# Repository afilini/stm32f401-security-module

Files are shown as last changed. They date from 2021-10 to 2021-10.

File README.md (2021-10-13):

# STM32F401 Security Module

<div style="width: 100%; display: flex; justify-content: space-between;">
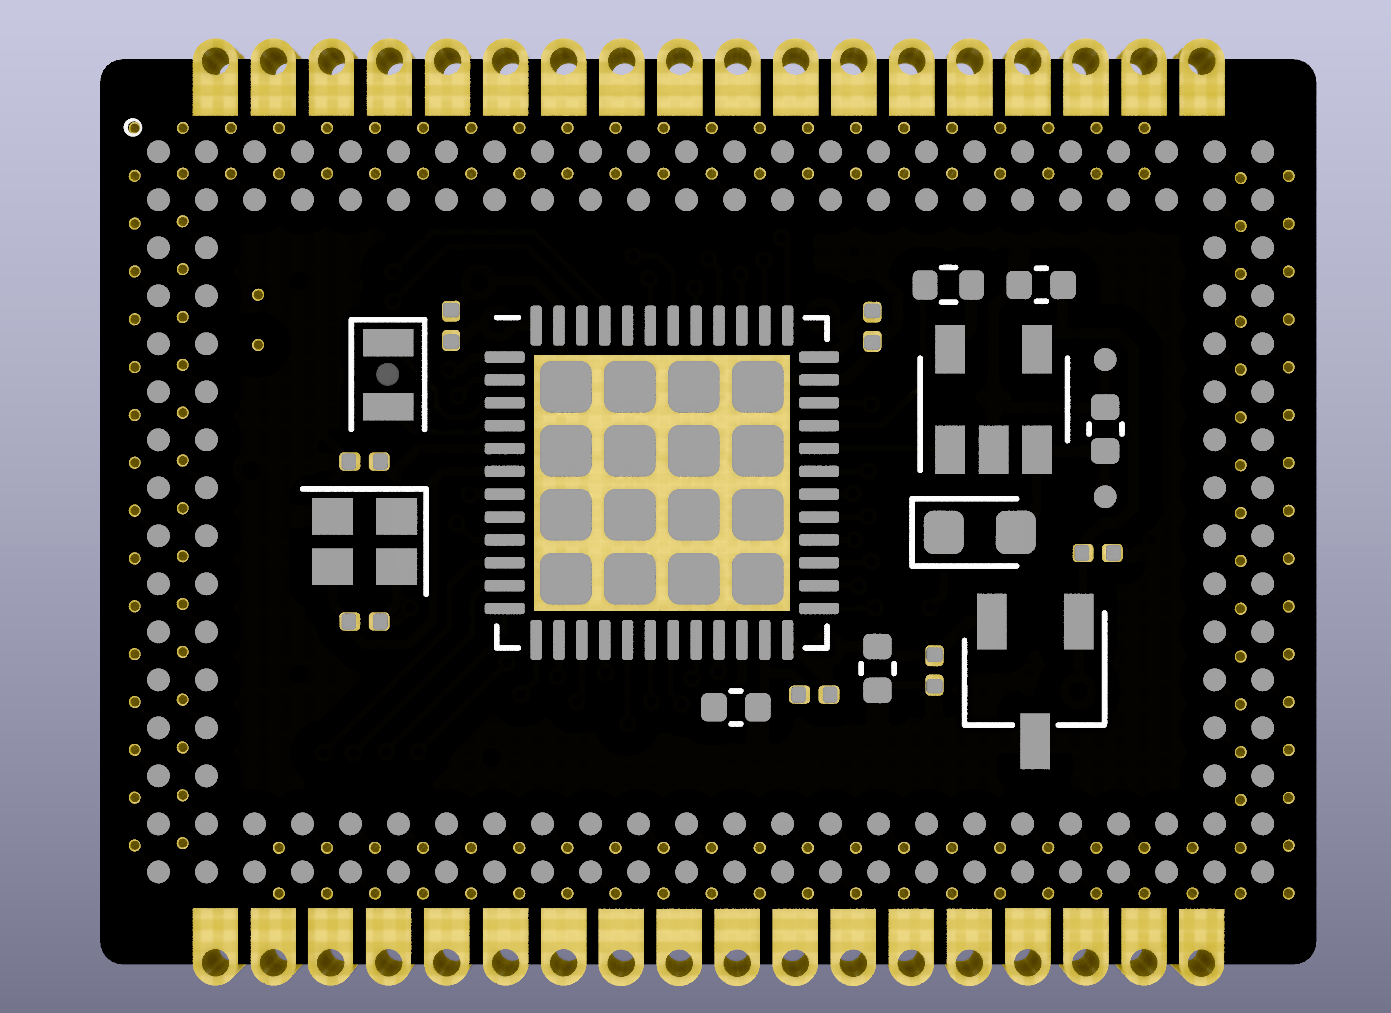
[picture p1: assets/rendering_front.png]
  
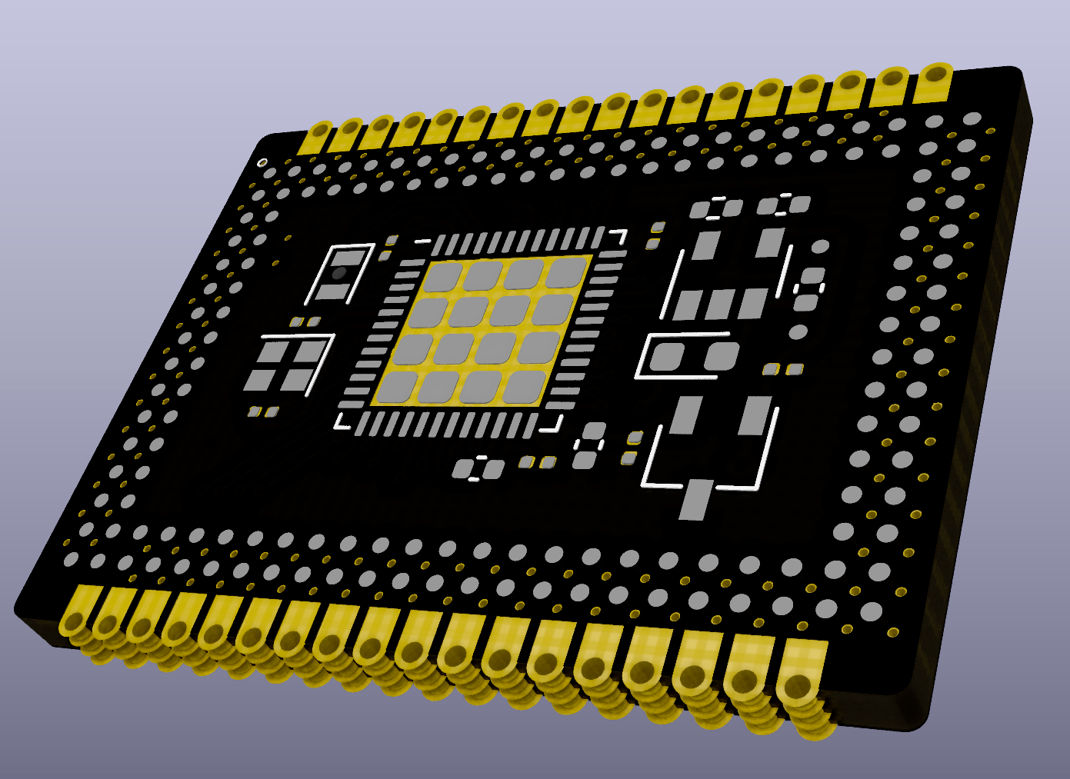
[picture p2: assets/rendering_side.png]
  
</div>

## License

This work is licensed under the [CERN Open Hardware Licence Version 2 - Strongly Reciprocal](LICENSE) license.

## Supporters

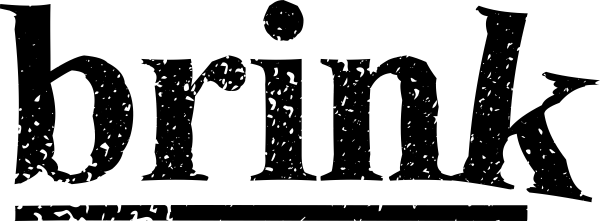
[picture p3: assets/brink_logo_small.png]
Brink logo


This work is supported by a [Brink](https://brink.dev) grant.

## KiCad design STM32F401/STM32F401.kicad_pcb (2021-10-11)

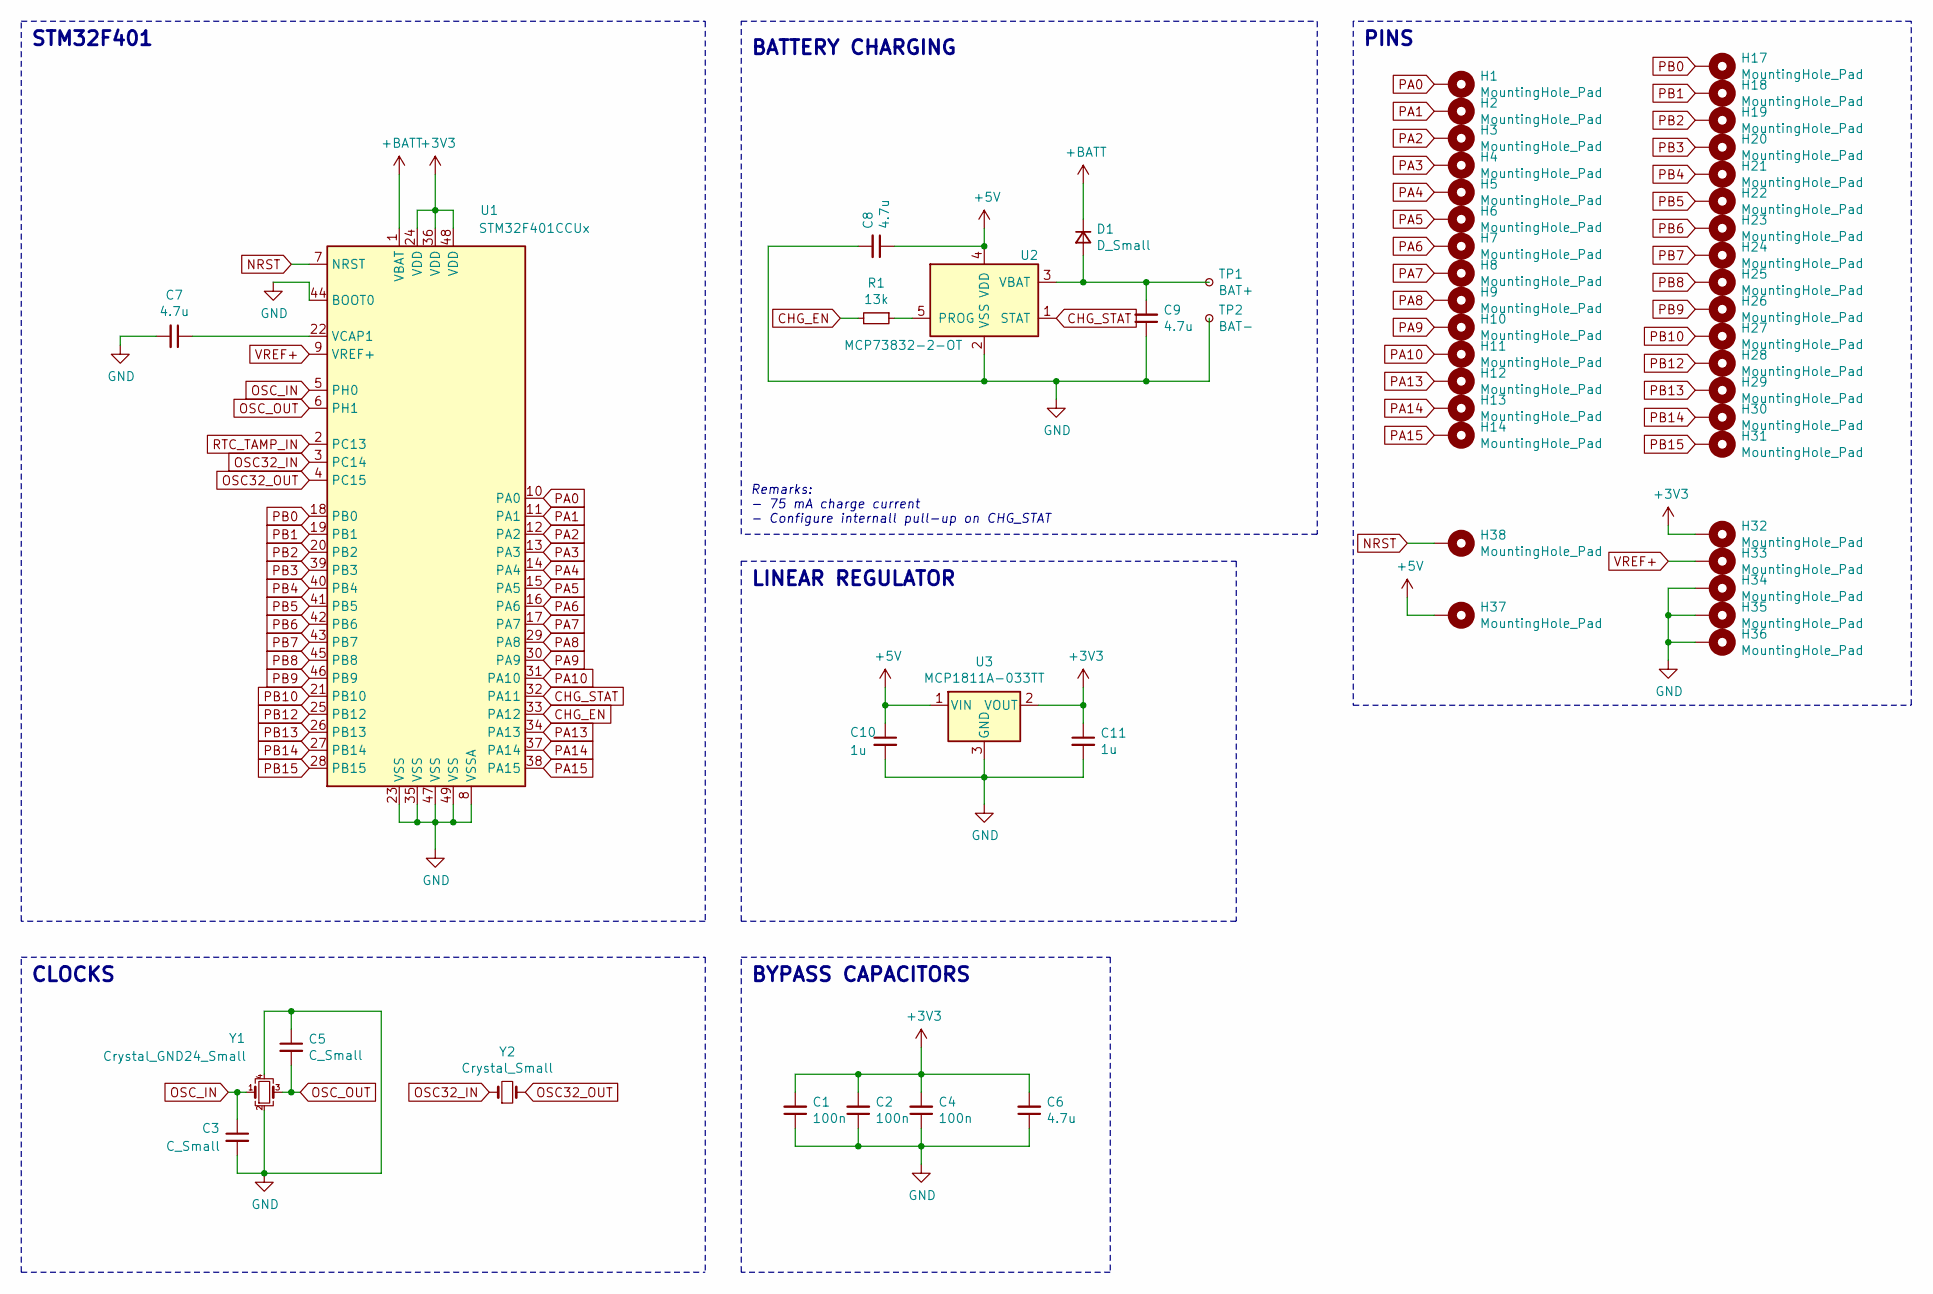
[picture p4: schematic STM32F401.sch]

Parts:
C1, C2, C4: 100n; C_0201_0603Metric
C3, C5: C_Small; C_0201_0603Metric
C6, C7, C8, C9: 4.7u; C_0402_1005Metric
C10, C11: 1u; C_0201_0603Metric
D1: D_Small; D_0603_1608Metric
H1, H2, H3, H4, H5, H6, H7, H8, H9, H10, H11, H12, H13, H14, H17, H18, H19, H20, H21, H22, H23, H24, H25, H26, H27, H28, H29, H30, H31, H32, H33, H34, H35, H36, H37, H38: MountingHole_Pad; CastellatedHole_0.6mm
R1: 13k; R_0402_1005Metric
TP1: BAT+; BatteryPad
TP2: BAT-; BatteryPad
U1: STM32F401CCUx; QFN-48-1EP_7x7mm_P0.5mm_EP5.6x5.6mm
U2: MCP73832-2-OT; SOT-23-5
U3: MCP1811A-033TT; TSOT-23
Y1: Crystal_GND24_Small; Crystal_SMD_2016-4Pin_2.0x1.6mm
Y2: Crystal_Small; Crystal_SMD_2012-2Pin_2.0x1.2mm

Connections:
+3V3: C1.2, C2.2, C4.2, C6.2, C11.1, H32.1, U1.24 (VDD), U1.36 (VDD), U1.48 (VDD), U3.2 (VOUT)
+5V: C8.1, C10.1, H37.1, U2.4 (VDD), U3.1 (VIN)
+BATT: D1.1 (K), U1.1 (VBAT)
CHG_EN: R1.2, U1.33 (PA12)
CHG_STAT: U1.32 (PA11), U2.1 (STAT)
GND: C1.1, C2.1, C3.2, C4.1, C5.1, C6.1, C7.2, C8.2, C9.1, C10.2, C11.2, H34.1, H35.1, H36.1, TP2.1, U1.8 (VSSA), U1.23 (VSS), U1.35 (VSS), U1.44 (BOOT0), U1.47 (VSS), U1.49 (VSS), U2.2 (VSS), U3.3 (GND), Y1.2, Y1.4
NRST: H38.1, U1.7 (NRST)
unnamed: C7.1, U1.22 (VCAP1)
unnamed: C9.2, D1.2 (A), TP1.1, U2.3 (VBAT)
unnamed: R1.1, U2.5 (PROG)
OSC32_IN: U1.3 (PC14), Y2.1
OSC32_OUT: U1.4 (PC15), Y2.2
OSC_IN: C3.1, U1.5 (PH0), Y1.1
OSC_OUT: C5.2, U1.6 (PH1), Y1.3
PA0: H1.1, U1.10 (PA0)
PA1: H2.1, U1.11 (PA1)
PA2: H3.1, U1.12 (PA2)
PA3: H4.1, U1.13 (PA3)
PA4: H5.1, U1.14 (PA4)
PA5: H6.1, U1.15 (PA5)
PA6: H7.1, U1.16 (PA6)
PA7: H8.1, U1.17 (PA7)
PA8: H9.1, U1.29 (PA8)
PA9: H10.1, U1.30 (PA9)
PA10: H11.1, U1.31 (PA10)
PA13: H12.1, U1.34 (PA13)
PA14: H13.1, U1.37 (PA14)
PA15: H14.1, U1.38 (PA15)
PB0: H17.1, U1.18 (PB0)
PB1: H18.1, U1.19 (PB1)
PB2: H19.1, U1.20 (PB2)
PB3: H20.1, U1.39 (PB3)
PB4: H21.1, U1.40 (PB4)
PB5: H22.1, U1.41 (PB5)
PB6: H23.1, U1.42 (PB6)
PB7: H24.1, U1.43 (PB7)
PB8: H25.1, U1.45 (PB8)
PB9: H26.1, U1.46 (PB9)
PB10: H27.1, U1.21 (PB10)
PB12: H28.1, U1.25 (PB12)
PB13: H29.1, U1.26 (PB13)
PB14: H30.1, U1.27 (PB14)
PB15: H31.1, U1.28 (PB15)
RTC_TAMP_IN: U1.2 (PC13)
VREF+: H33.1, U1.9 (VREF+)

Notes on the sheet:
STM32F401
CLOCKS
BYPASS CAPACITORS
LINEAR REGULATOR
BATTERY CHARGING
PINS
Remarks: - 75 mA charge current - Configure internall pull-up on CHG_STAT

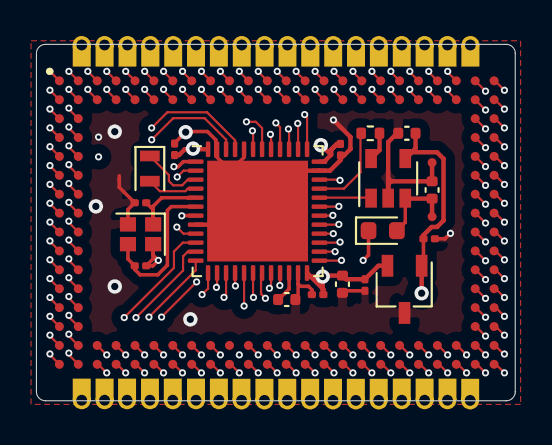
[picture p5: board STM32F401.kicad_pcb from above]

Board: 4 copper layers, 26.6 x 19.8 mm, 56 parts (0 on the bottom side), 44 nets.
